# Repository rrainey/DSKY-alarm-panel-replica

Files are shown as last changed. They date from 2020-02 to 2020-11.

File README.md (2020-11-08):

# DSKY Alarm Indicator Panel Replica

## The current PCB layout has passed testing.

This is a scale functional replica of the Alarm Indicator panel for the Apollo Guidance Computer. It is
designed to be part of a larger replica of the Display and Keyboard (DSKY) module of the AGC.

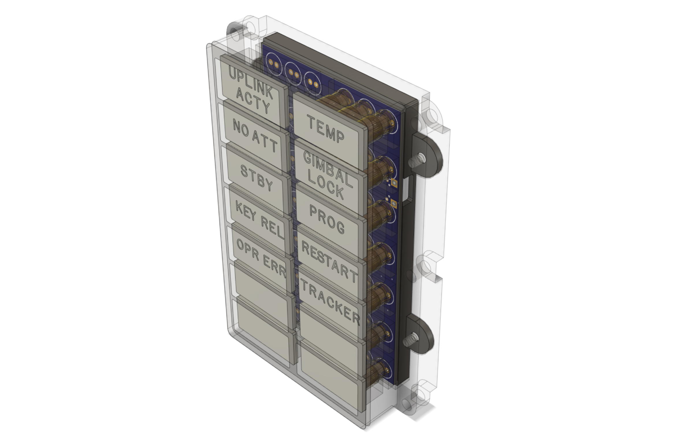
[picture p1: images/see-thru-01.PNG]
See through view


This project is composed of these component subfolders:

* artwork - artwork to be silk-screened onto the front transparent acrylic cover

* pcb - KiCad project for the controller PCB design

* firmware - circuitpython board definition and python-based test and controller firmware

* hardware - 3D-printable frame components designed using Fusion 360. STEP and Fusion source files available. Hardware models used in thie replica were derived from models found in the [AGC Mechanical CAD project](https://github.com/rrainey/agc-mechanical-cad).

## Exploded View of the Assembly

[This video](https://vimeo.com/393337269) will give you a sense of the internal construction of the unit. The panel
is a combinaton of white and yellow indicators. Like the original, incendescent lamps are used for each alarm
indicator. Yellow bezel inserts supply the indictor color where needed. An AT SAMD21 microcontroller drives the lamp from a 5V DC power
source. This microcontroller includes an I2C interface designed to be the source for external control of the unit.
There's also a USB interface, however, that's more for programming than operational use.

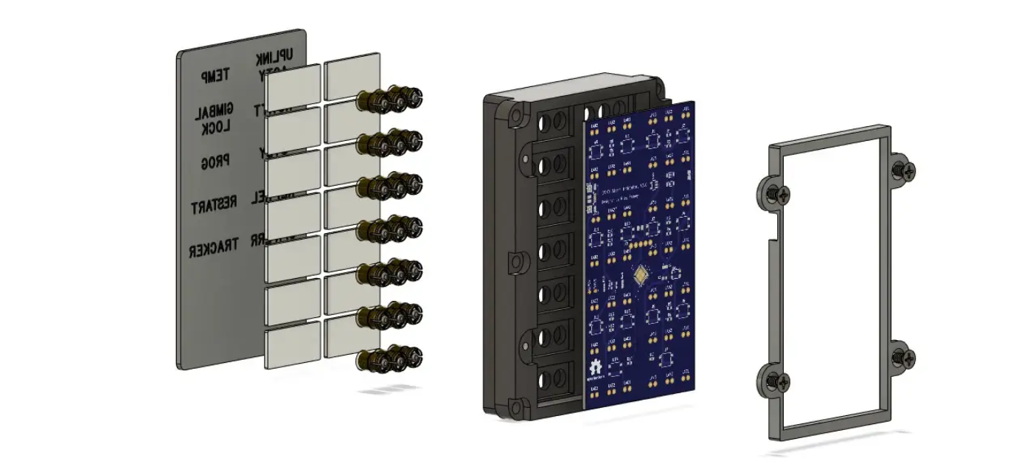
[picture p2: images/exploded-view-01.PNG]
Exploded view


At the top is a clear acrylic plate (0.060" thick). On that, I silkscreen lamp labels and the frame outline. Below that, there are 14 translucent covers, one for each indicator lamp array. Each indicator is composed of three incandescent lamps. Yellow bezels are inserted where needed. The bezels and the translucent covers snap into the main body of the component.  

A lamp and microcontroller PCB slides into a recess under the main body.  This PCB is held in place by a frame. The frame is secured with screws. The main body and PCB frame are both designed to be 3D printed from Nylon, ABS, or PLA.

## Painting

The original NASA drawings for all variants of this component, [1006387D for example,](https://archive.org/stream/apertureCardBox439Part2NARASW_images#page/n409/mode/1up) point to [this NASA paint specification [1008809-1]](https://archive.org/stream/apertureCardBox443NARASW_images#page/n504/mode/1up). It states [FED-STD 36231](http://federalstandard595.com/36231/) as the external color of the unit.  Good quality historial photos (examples [here](https://www.icollector.com/Apollo-CM-DSKY_i21861898) and [here](http://nassp.sourceforge.net/wiki/File:DSKY.jpg)) seem to imply a slightly different shade of gray, though. 

I haven't decided how to reconcile this difference yet. I may custom mix using Nazdar pigments, or I might simply use [an aircraft-grade epoxy premix](https://www.skygeek.com/deft-01-series-epoxy-topcoat-gray-36231-mil-prf-227750g.html) of FS36231.

## Credits and Related Projects

This project is inspired by work by Ben Krasnow creating a DSKY Electroluminescent Panel replica. You'll
find information about that project in [this Applied Science video](https://www.youtube.com/watch?v=Z2o_Sp2-aBo) by Ben. Like Ben's E/L display, this project is driven by an AT SAMD21 microcontroller chip; the same chip is used in the multiple Adafruit microcontroller boards, including the Adafruit Trinket M0.

## DSKY Alarm Indicator Replica License

Creative Commons Attribution/Share-Alike, all text above must be included in any redistribution. See license.txt for additional details.

## Adafruit Trinket M0 License

This project includes hardware design elements from the Adafruit [Trinket M0 PCB project](https://github.com/adafruit/Adafruit-Trinket-M0-PCB). Adafruit invests time and resources providing this open source design, please support Adafruit and open-source hardware by purchasing products from [Adafruit](https://www.adafruit.com)!

The Trinket M0 was designed by Limor Fried/Ladyada for Adafruit Industries.

Creative Commons Attribution/Share-Alike, all text above must be included in any redistribution. See license.txt for additional details.

## My Background

My name is Riley Rainey. I'm a software developer by profession. I spent a number of years building aerospace simulations as my day job.

## Getting Support

There's no official support available, but you can [leave comments or create an issue](https://github.com/rrainey/DSKY-alarm-panel-replica/issues) in this GitHub project.

  
This work is licensed under a [Creative Commons Attribution-ShareAlike 4.0 International License](http://creativecommons.org/licenses/by-sa/4.0/).

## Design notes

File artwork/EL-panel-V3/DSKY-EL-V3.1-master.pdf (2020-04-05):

DSKY-EL-V3.1-master.psd @ 66.7% (Conductive, RGB/8) *

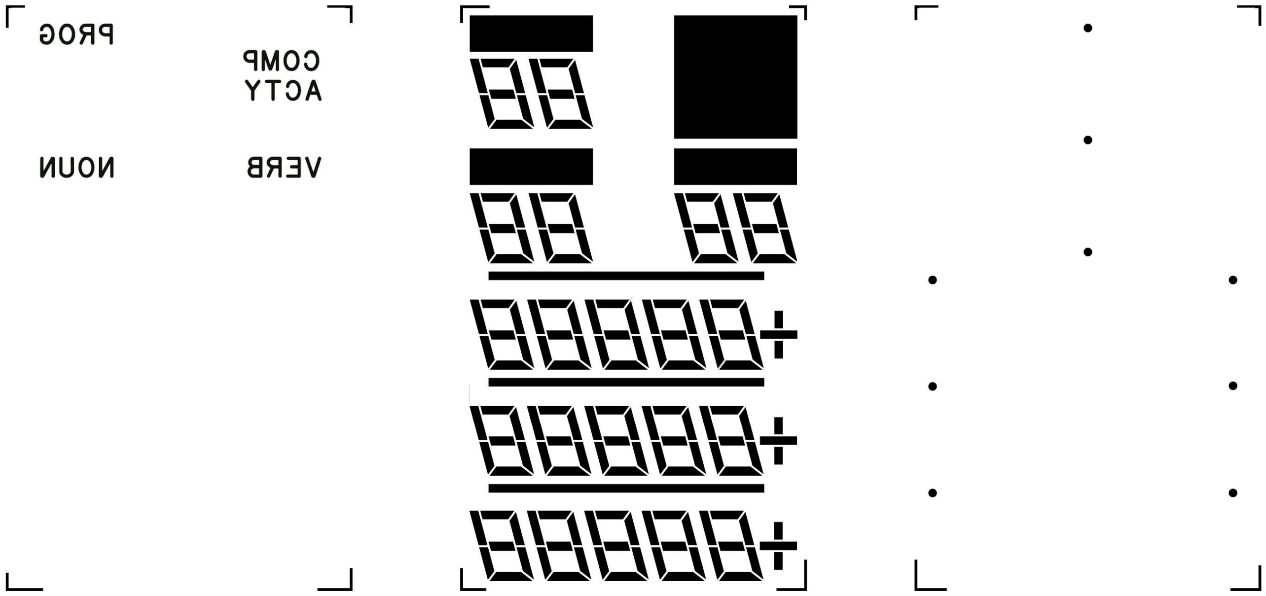
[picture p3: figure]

NOTE: ink laid down on the back side of ITO glass plate, so image appears reversed here. Glass dimensions 2.48x4.20 in.

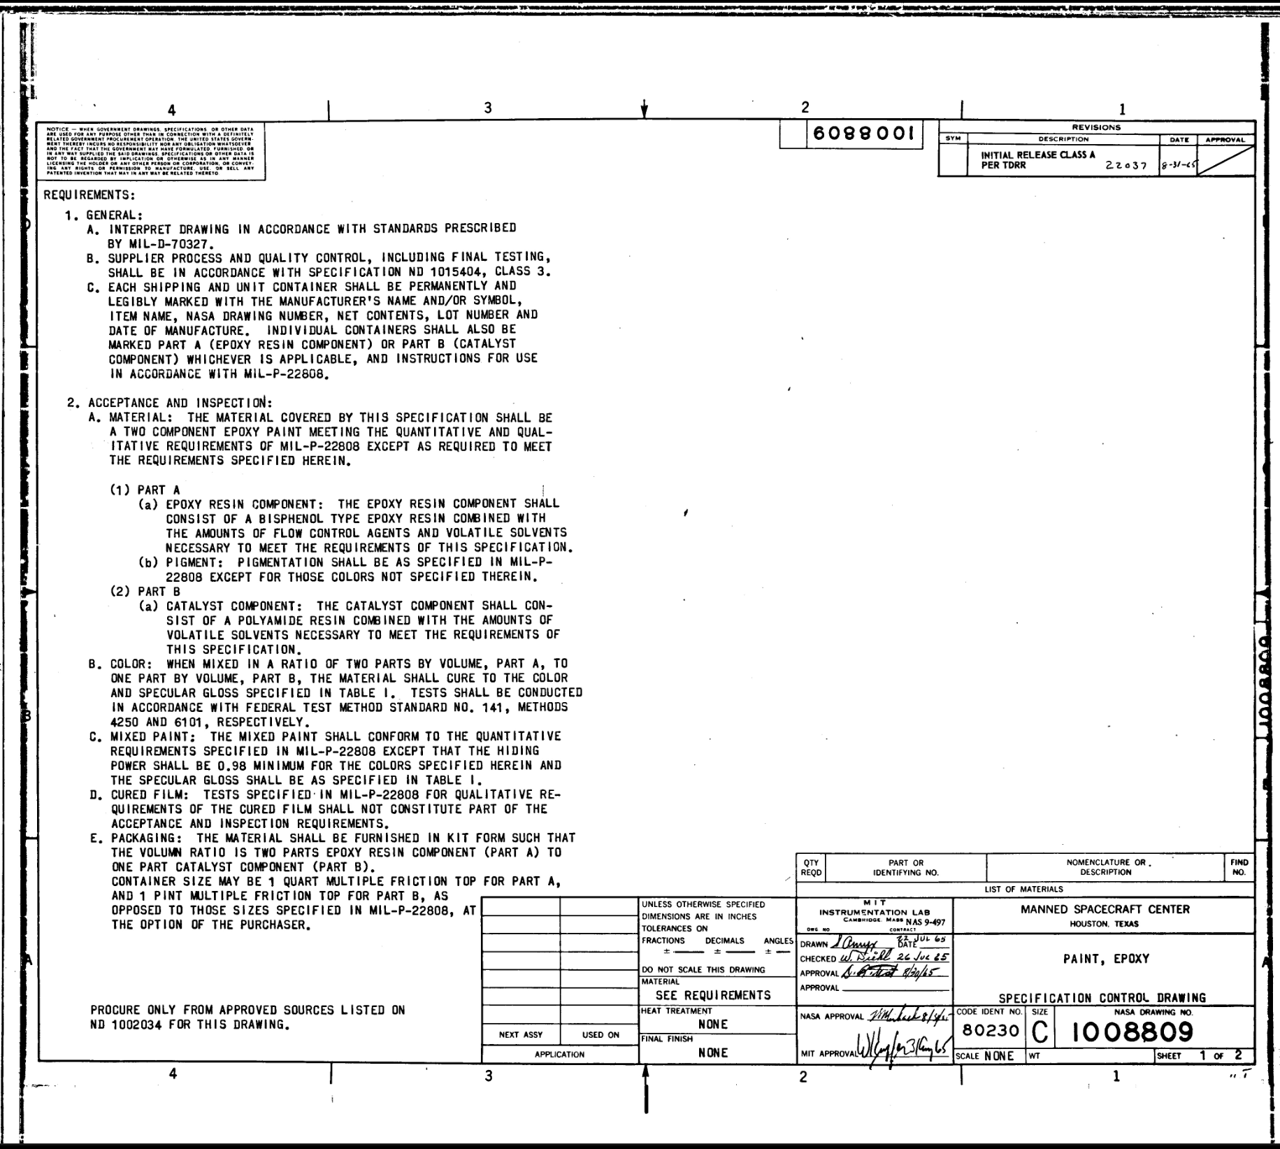
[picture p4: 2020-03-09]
images/1008809-1of2.PNG

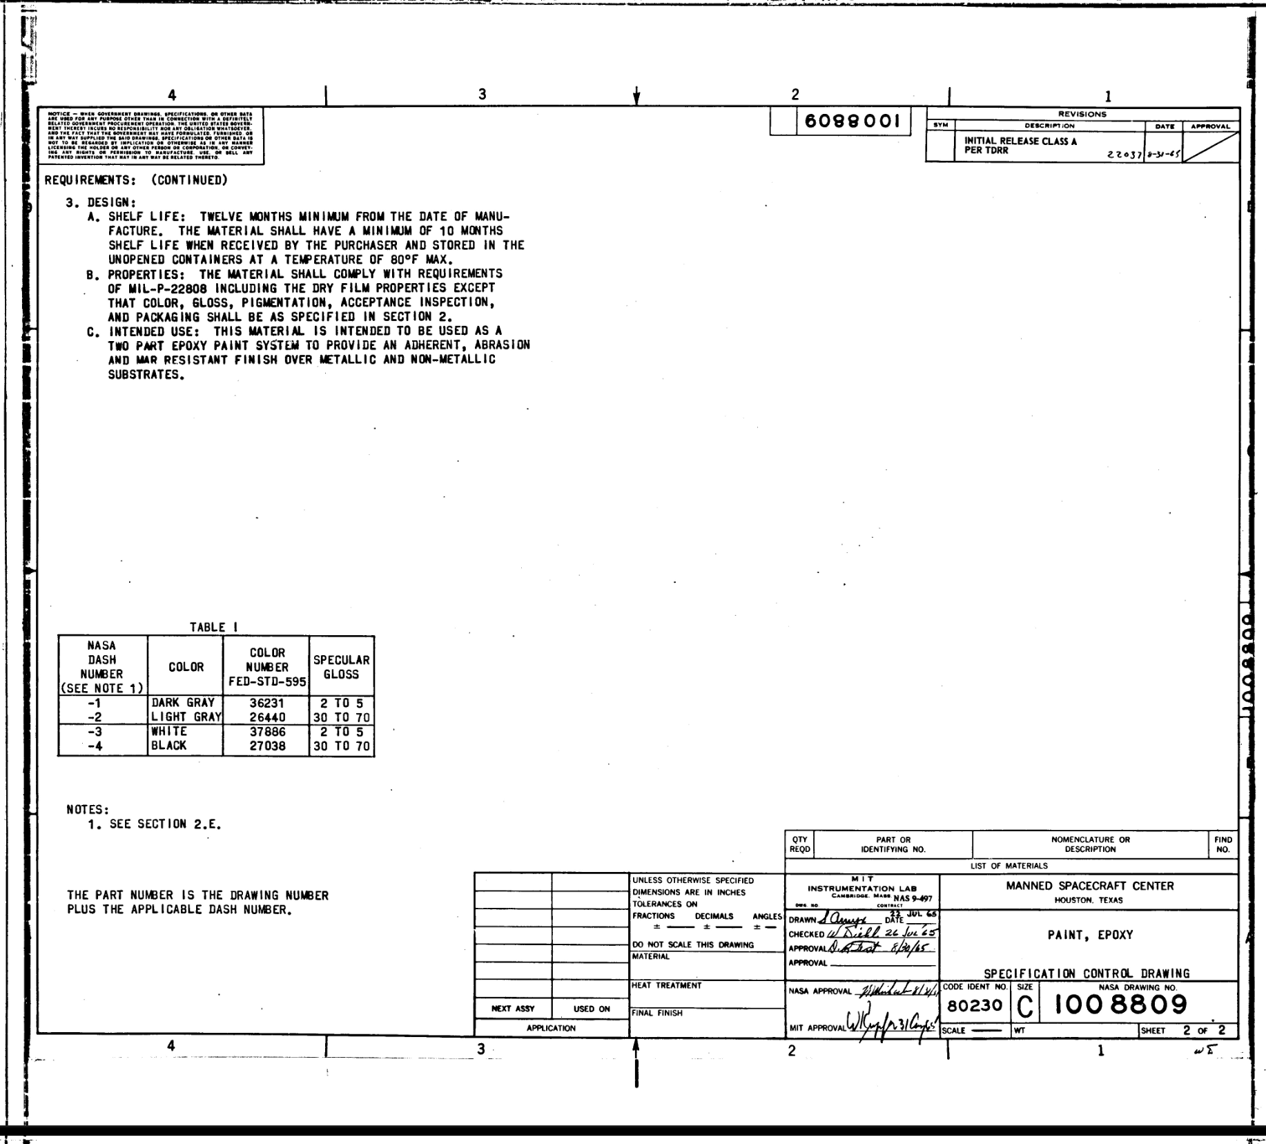
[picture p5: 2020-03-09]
images/100809-2of2.PNG

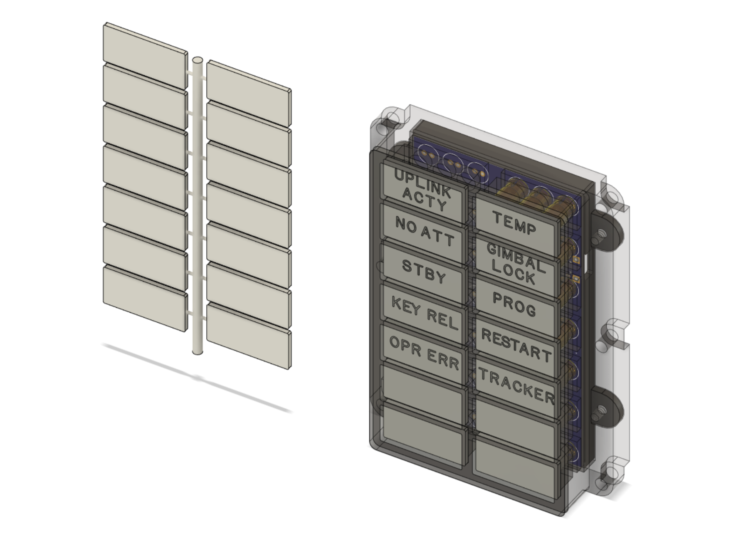
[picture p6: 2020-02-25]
images/insert-tree.PNG

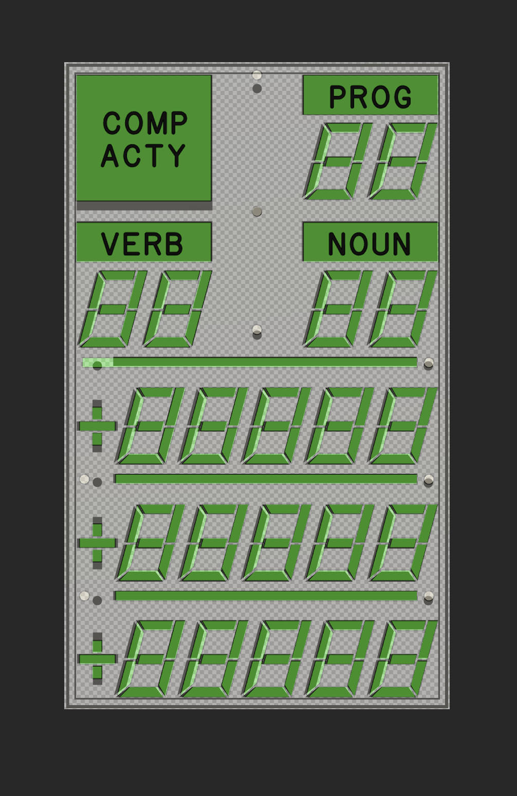
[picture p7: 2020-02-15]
artwork/EL-panel-V3/compare.PNG

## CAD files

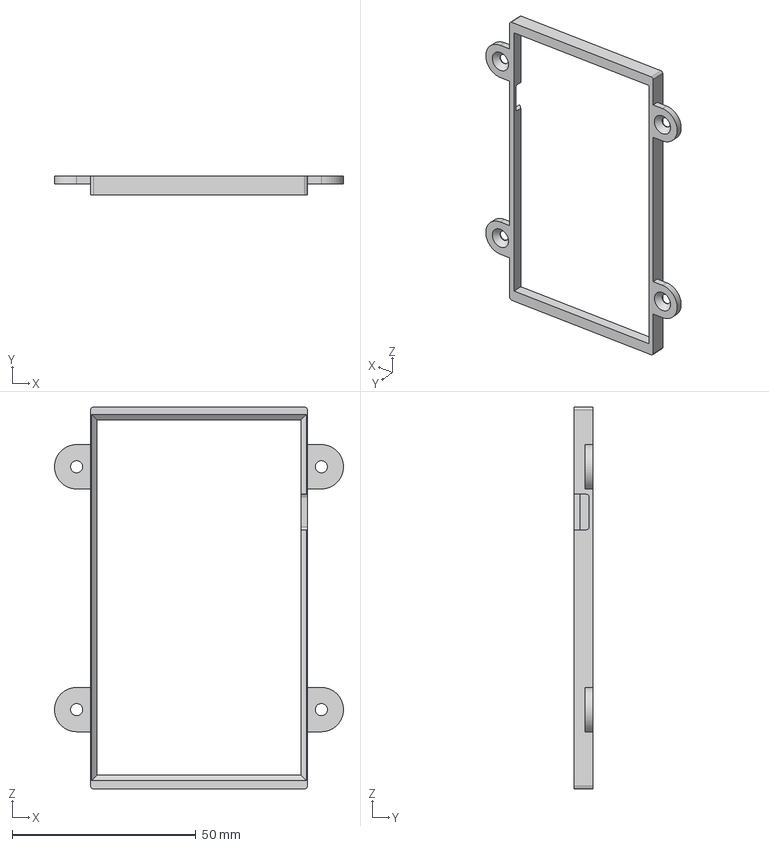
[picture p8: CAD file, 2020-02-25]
hardware/Retainer Plate.step
78.6 x 5.08 x 103.9 mm

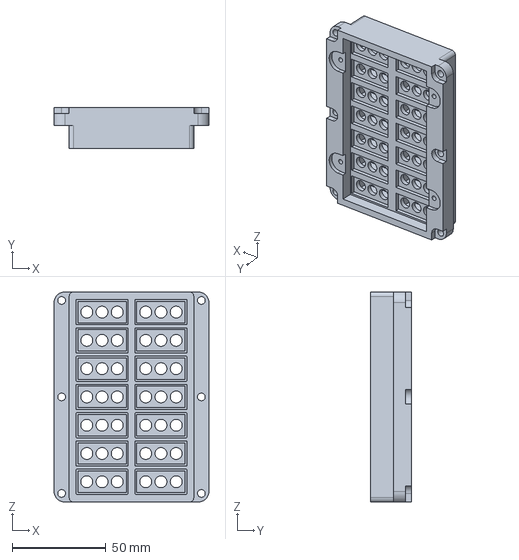
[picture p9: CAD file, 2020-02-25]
hardware/Frame.step
82.8 x 21.8 x 112.2 mm

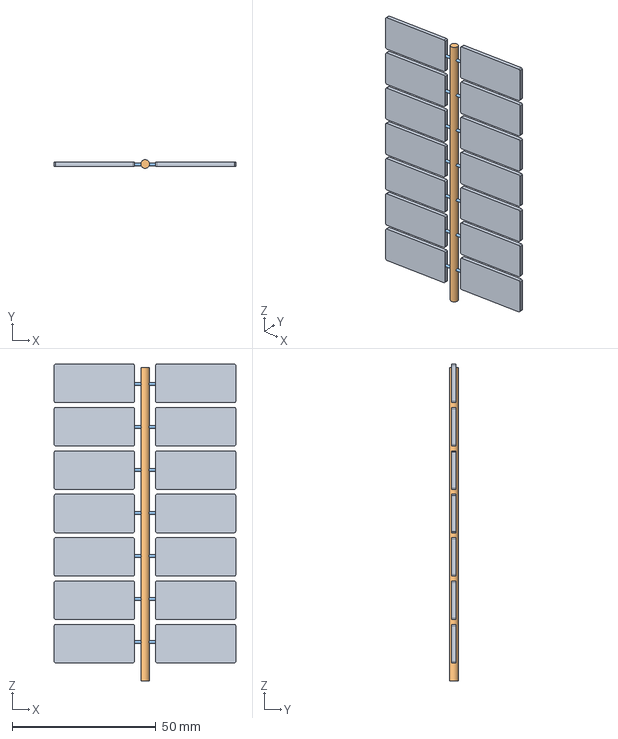
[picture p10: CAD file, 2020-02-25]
hardware/Translucent inserts tree.step
63.2 x 3.05 x 110.4 mm

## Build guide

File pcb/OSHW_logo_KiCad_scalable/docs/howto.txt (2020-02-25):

How to make your own:
---------------------

Watch / read this first:

* http://www.kicad-pcb.org/display/KICAD/Videos+by+zupnikal

The last two videos should be helpful for how to create a custom .emp file from images.

* http://www.re-innovation.co.uk/web12/index.php/en/blog-75/230-adding-logo-to-kicad

If you use linux (which you should), you don't have to use the online-scaler. Just use the scripts!

---

* Create a folder to hold your new footprint library.
* Copy the scripts 'make_lib.sh' and 'scale.pl' into that folder.
* Make sure these files are executable (chmod u+x ...).
* Copy your custom .emp file into that foler.

* Run the 'make_lib.sh' script as follows:

./make_lib.sh input-file.emp lib-name.mod START END

START and END are placeholders for positive integer numbers (1,2,3...) that determine
the range of created footprint sizes. The units are metric (mm).

The 'lib-name.mod' file will show up in the 'lib' sub-folder. Add it to your pcbnew
library settings as usual.

Footprints that are created for back-layers are automagically mirrored horizontally.
To place them onto a back-layer, hover the mouse-pointer over them and press 'f' for 'flip'.

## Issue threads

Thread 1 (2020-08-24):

Arduino build doesn't yet appear to support all output required output pins

rrainey, 2020-08-24:
I have modified the Adafruit trinket_m0 Arduino SAMD board definition to insert references to all output pins used by the design, but this isn't working quite yet.  See https://github.com/adafruit/ArduinoCore-samd

rrainey, 2020-09-25:
The modified board definition seems to be working. I'll publish the updated variant.cpp file separately.

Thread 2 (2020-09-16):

Merge into CircuitPython?

tannewt, 2020-09-16:
This is very cool! Do you plan on merging the board definition into main CircuitPython? We'd love to have it.

rrainey, 2020-09-26:
Ya. Let me back up a bit and look into it. I rewrote the I2C driver firmware as an Arduino sketch, however, that was mainly to be more consistent with Ben Krasnow's DSKY EL Driver project. I hadn't worked with CircuitPython before this project and I came to like it pretty quickly -- even with the board-specific changes that I needed to add. I have really enjoyed working with Adafruit's line of SAM boards and firmware. The openness is fabulous. It made for an easy jumping off point for creating these custom PCB designs. keep up the great work!

rrainey, 2020-09-26:
I'll spend some time on it this weekend. I see that my CircuitPython board definition requires a few digital pin additions to reflect the current lamp configuration. I'll send y'all a PR when I'm done.

tannewt, 2020-09-26:
Great! Feel free to check in on the Adafruit Discord if you have any questions: https://adafru.it/discord

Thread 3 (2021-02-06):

Bill of materials

vladamihailescu, 2021-02-06:
Hello Riley,

I was just wondering if you had a BOM for the alarm panel. The one I generated from your Kicad is missing the part numbers for the capacitors and diodes

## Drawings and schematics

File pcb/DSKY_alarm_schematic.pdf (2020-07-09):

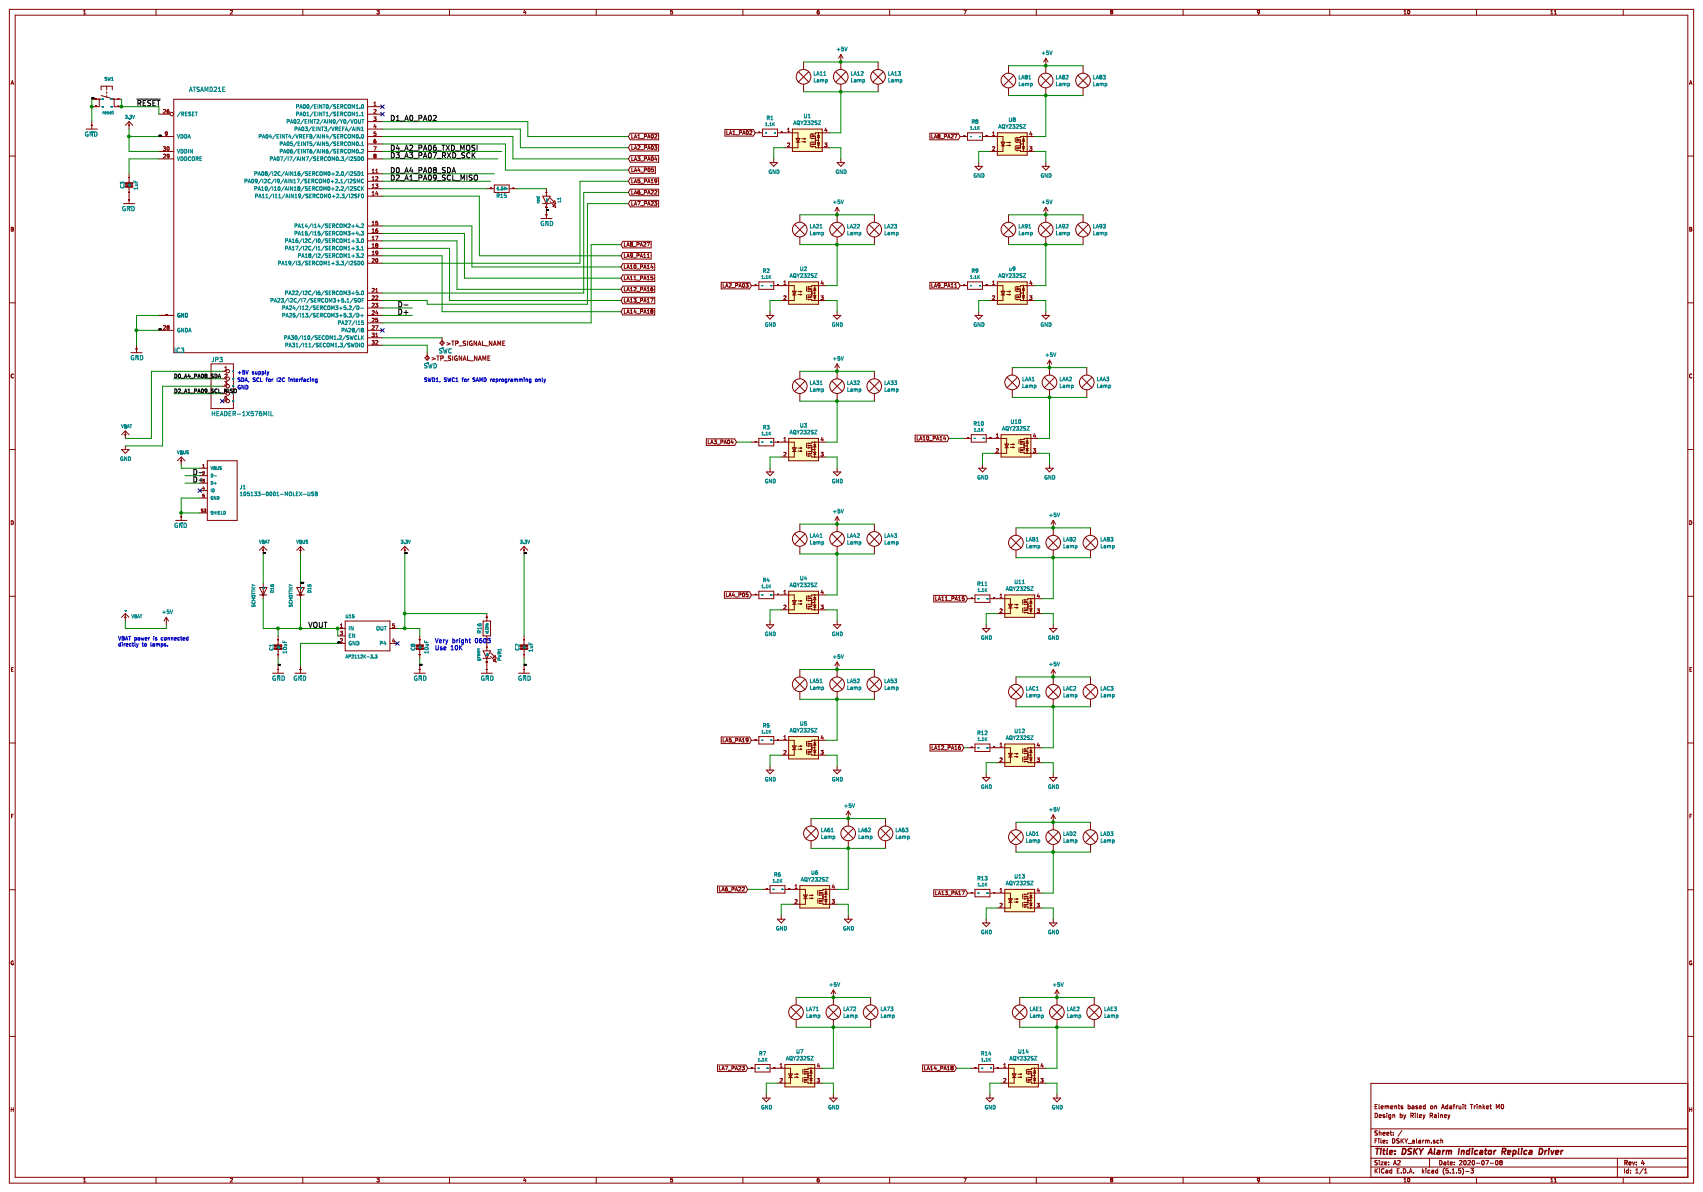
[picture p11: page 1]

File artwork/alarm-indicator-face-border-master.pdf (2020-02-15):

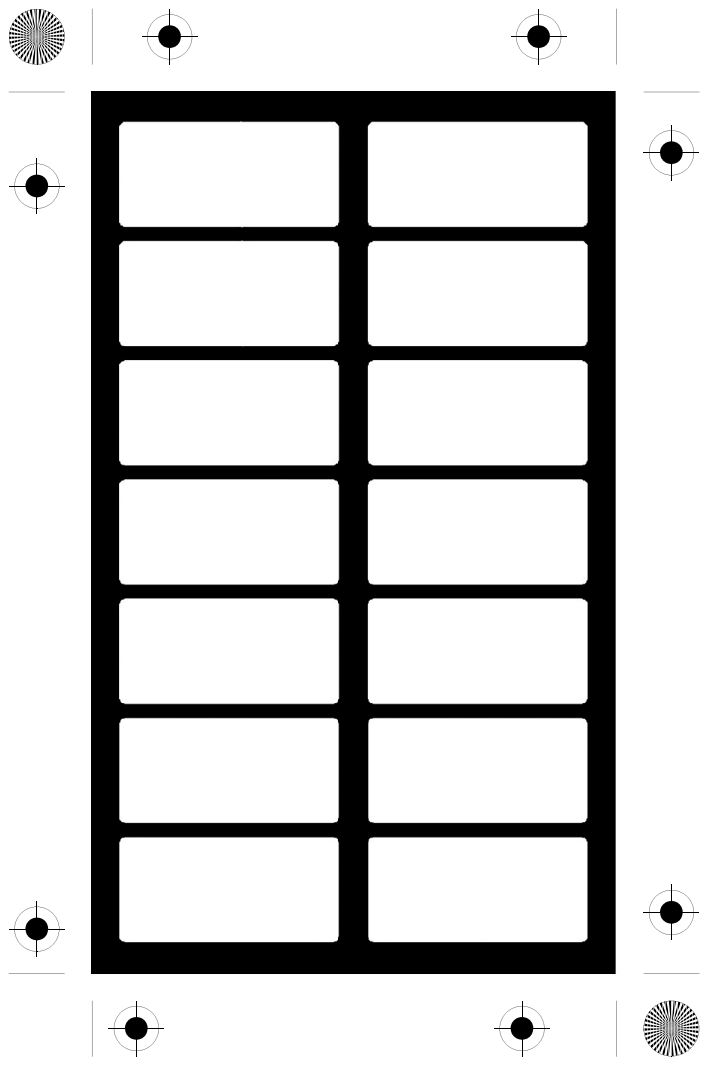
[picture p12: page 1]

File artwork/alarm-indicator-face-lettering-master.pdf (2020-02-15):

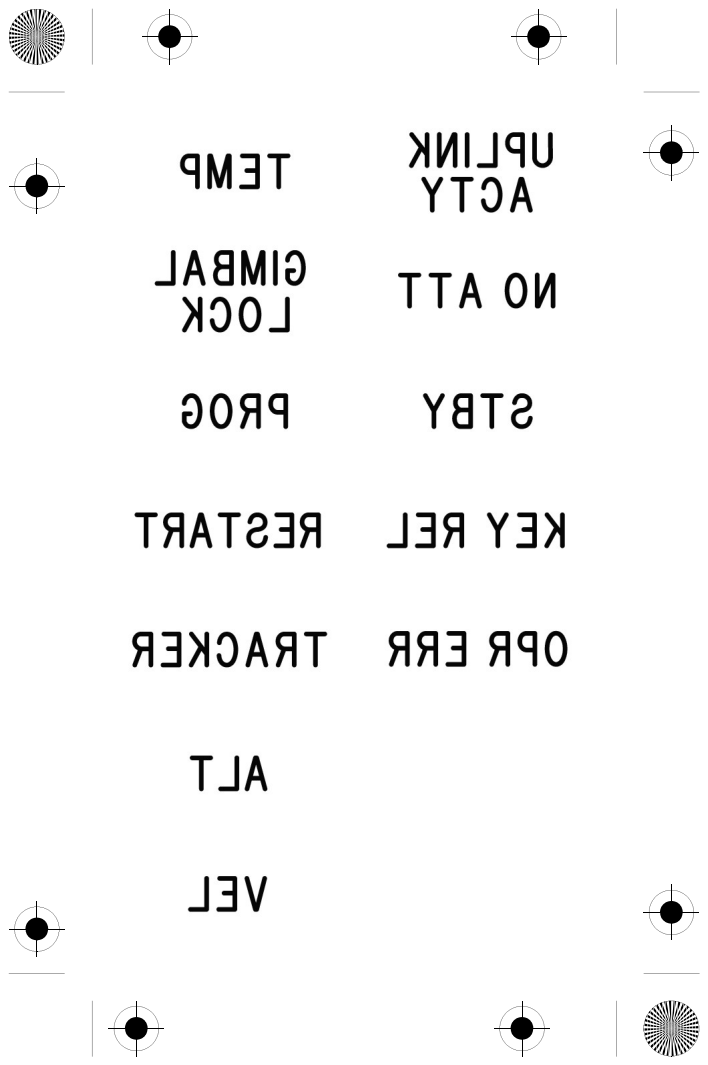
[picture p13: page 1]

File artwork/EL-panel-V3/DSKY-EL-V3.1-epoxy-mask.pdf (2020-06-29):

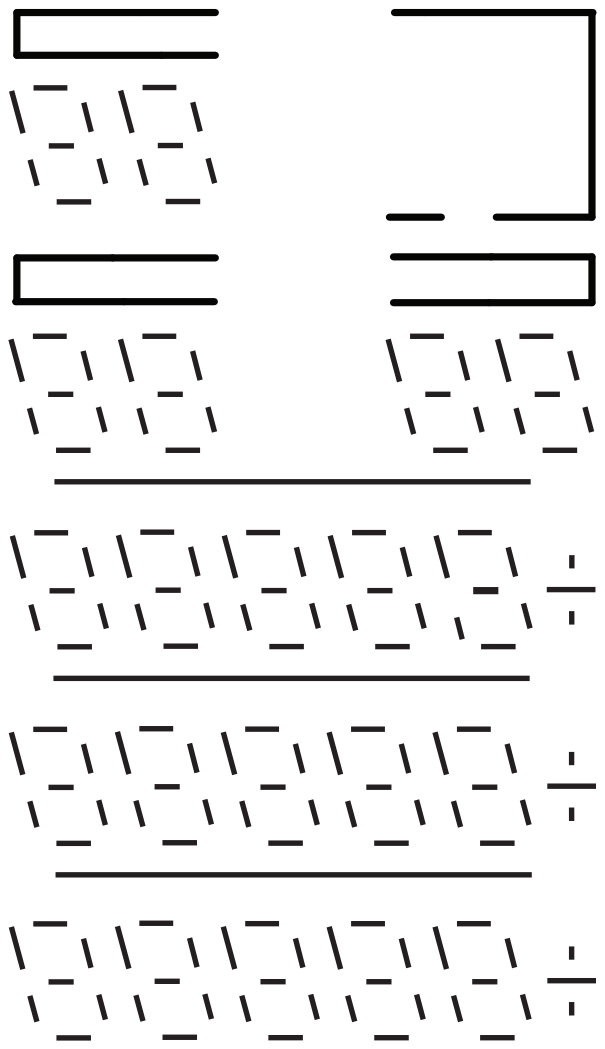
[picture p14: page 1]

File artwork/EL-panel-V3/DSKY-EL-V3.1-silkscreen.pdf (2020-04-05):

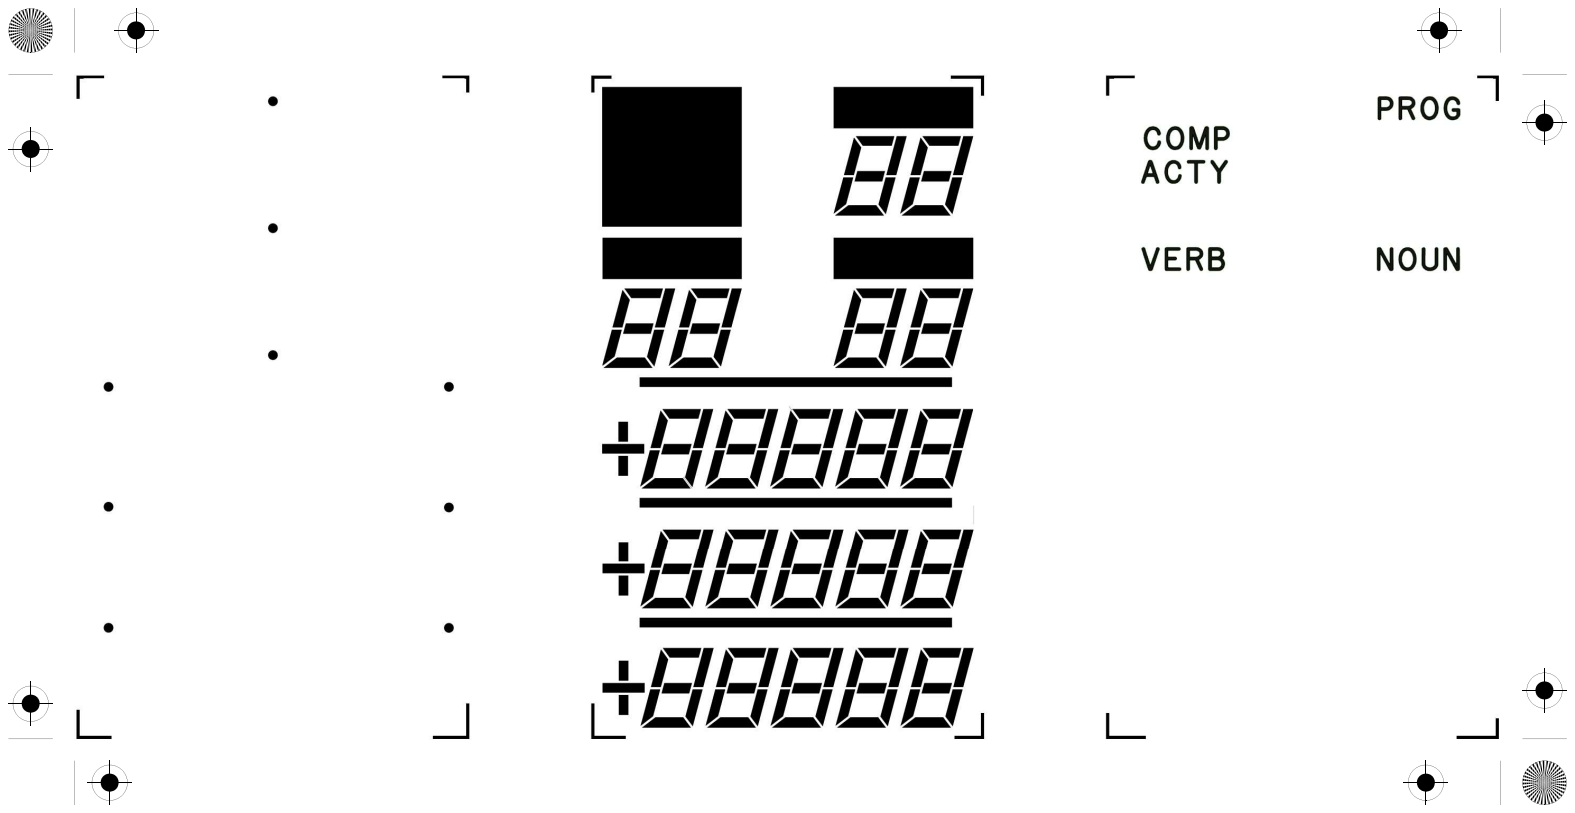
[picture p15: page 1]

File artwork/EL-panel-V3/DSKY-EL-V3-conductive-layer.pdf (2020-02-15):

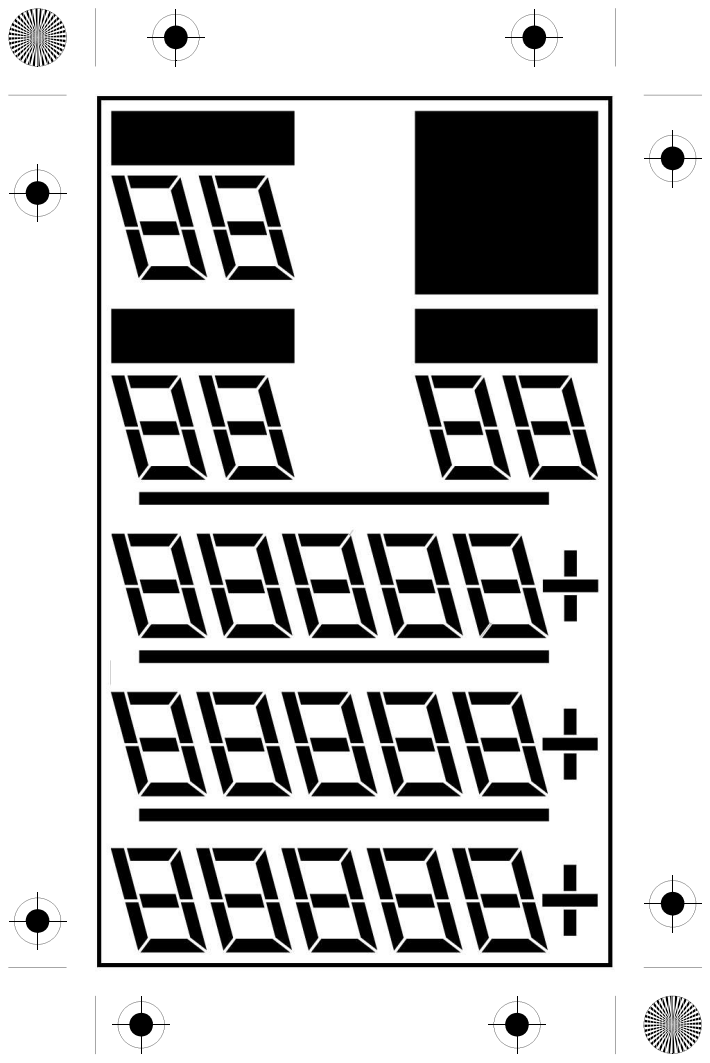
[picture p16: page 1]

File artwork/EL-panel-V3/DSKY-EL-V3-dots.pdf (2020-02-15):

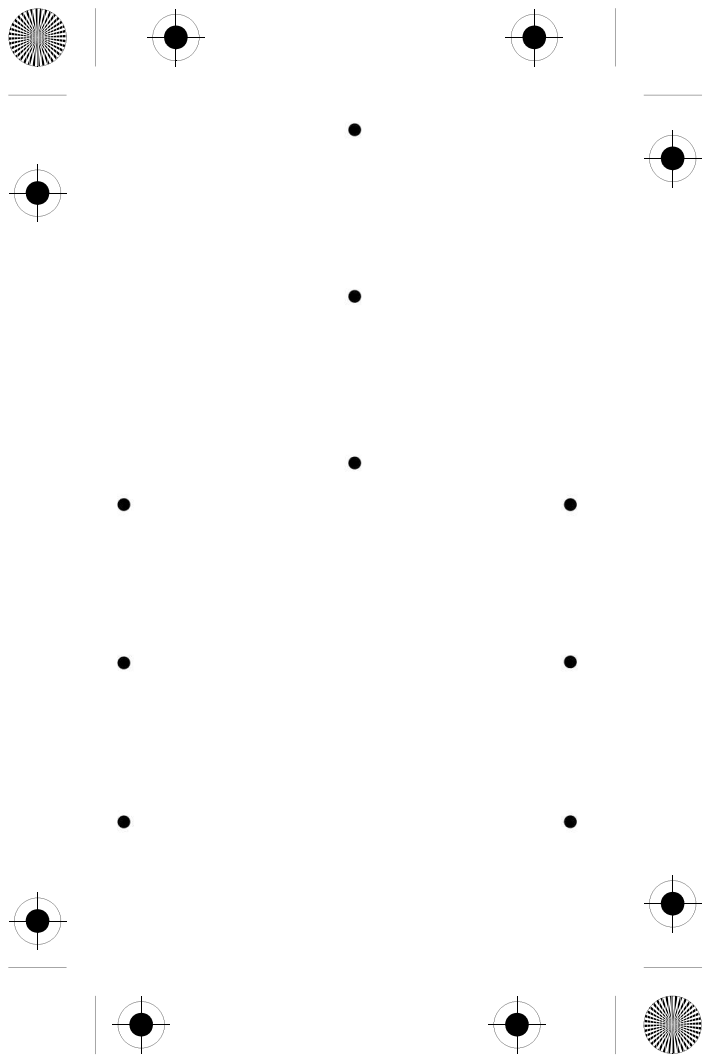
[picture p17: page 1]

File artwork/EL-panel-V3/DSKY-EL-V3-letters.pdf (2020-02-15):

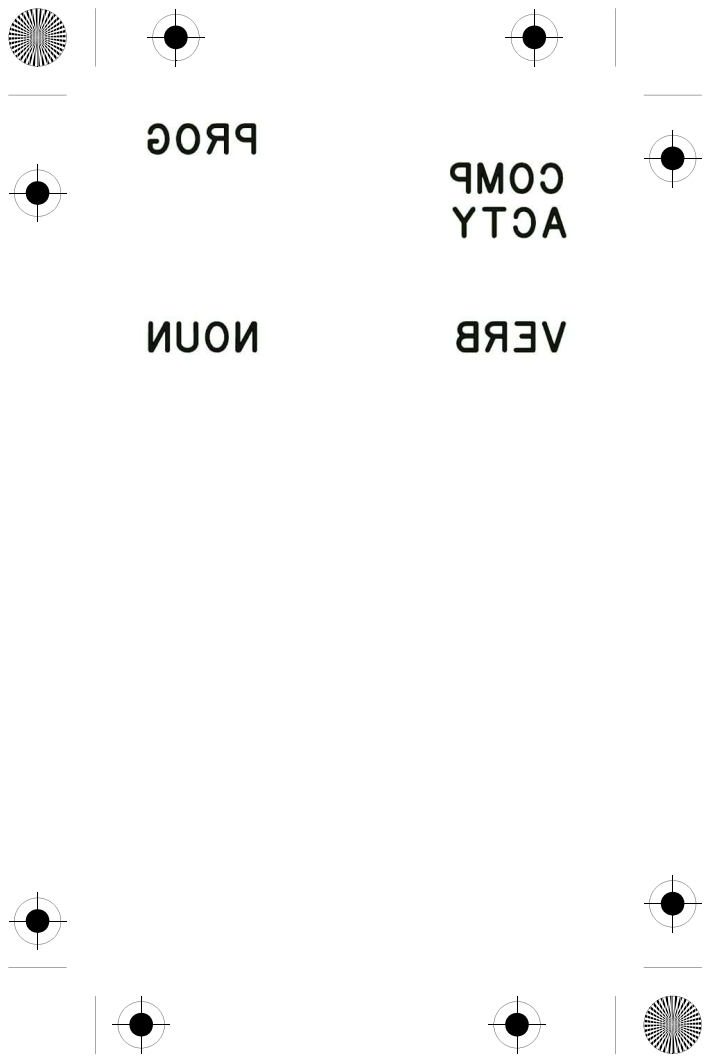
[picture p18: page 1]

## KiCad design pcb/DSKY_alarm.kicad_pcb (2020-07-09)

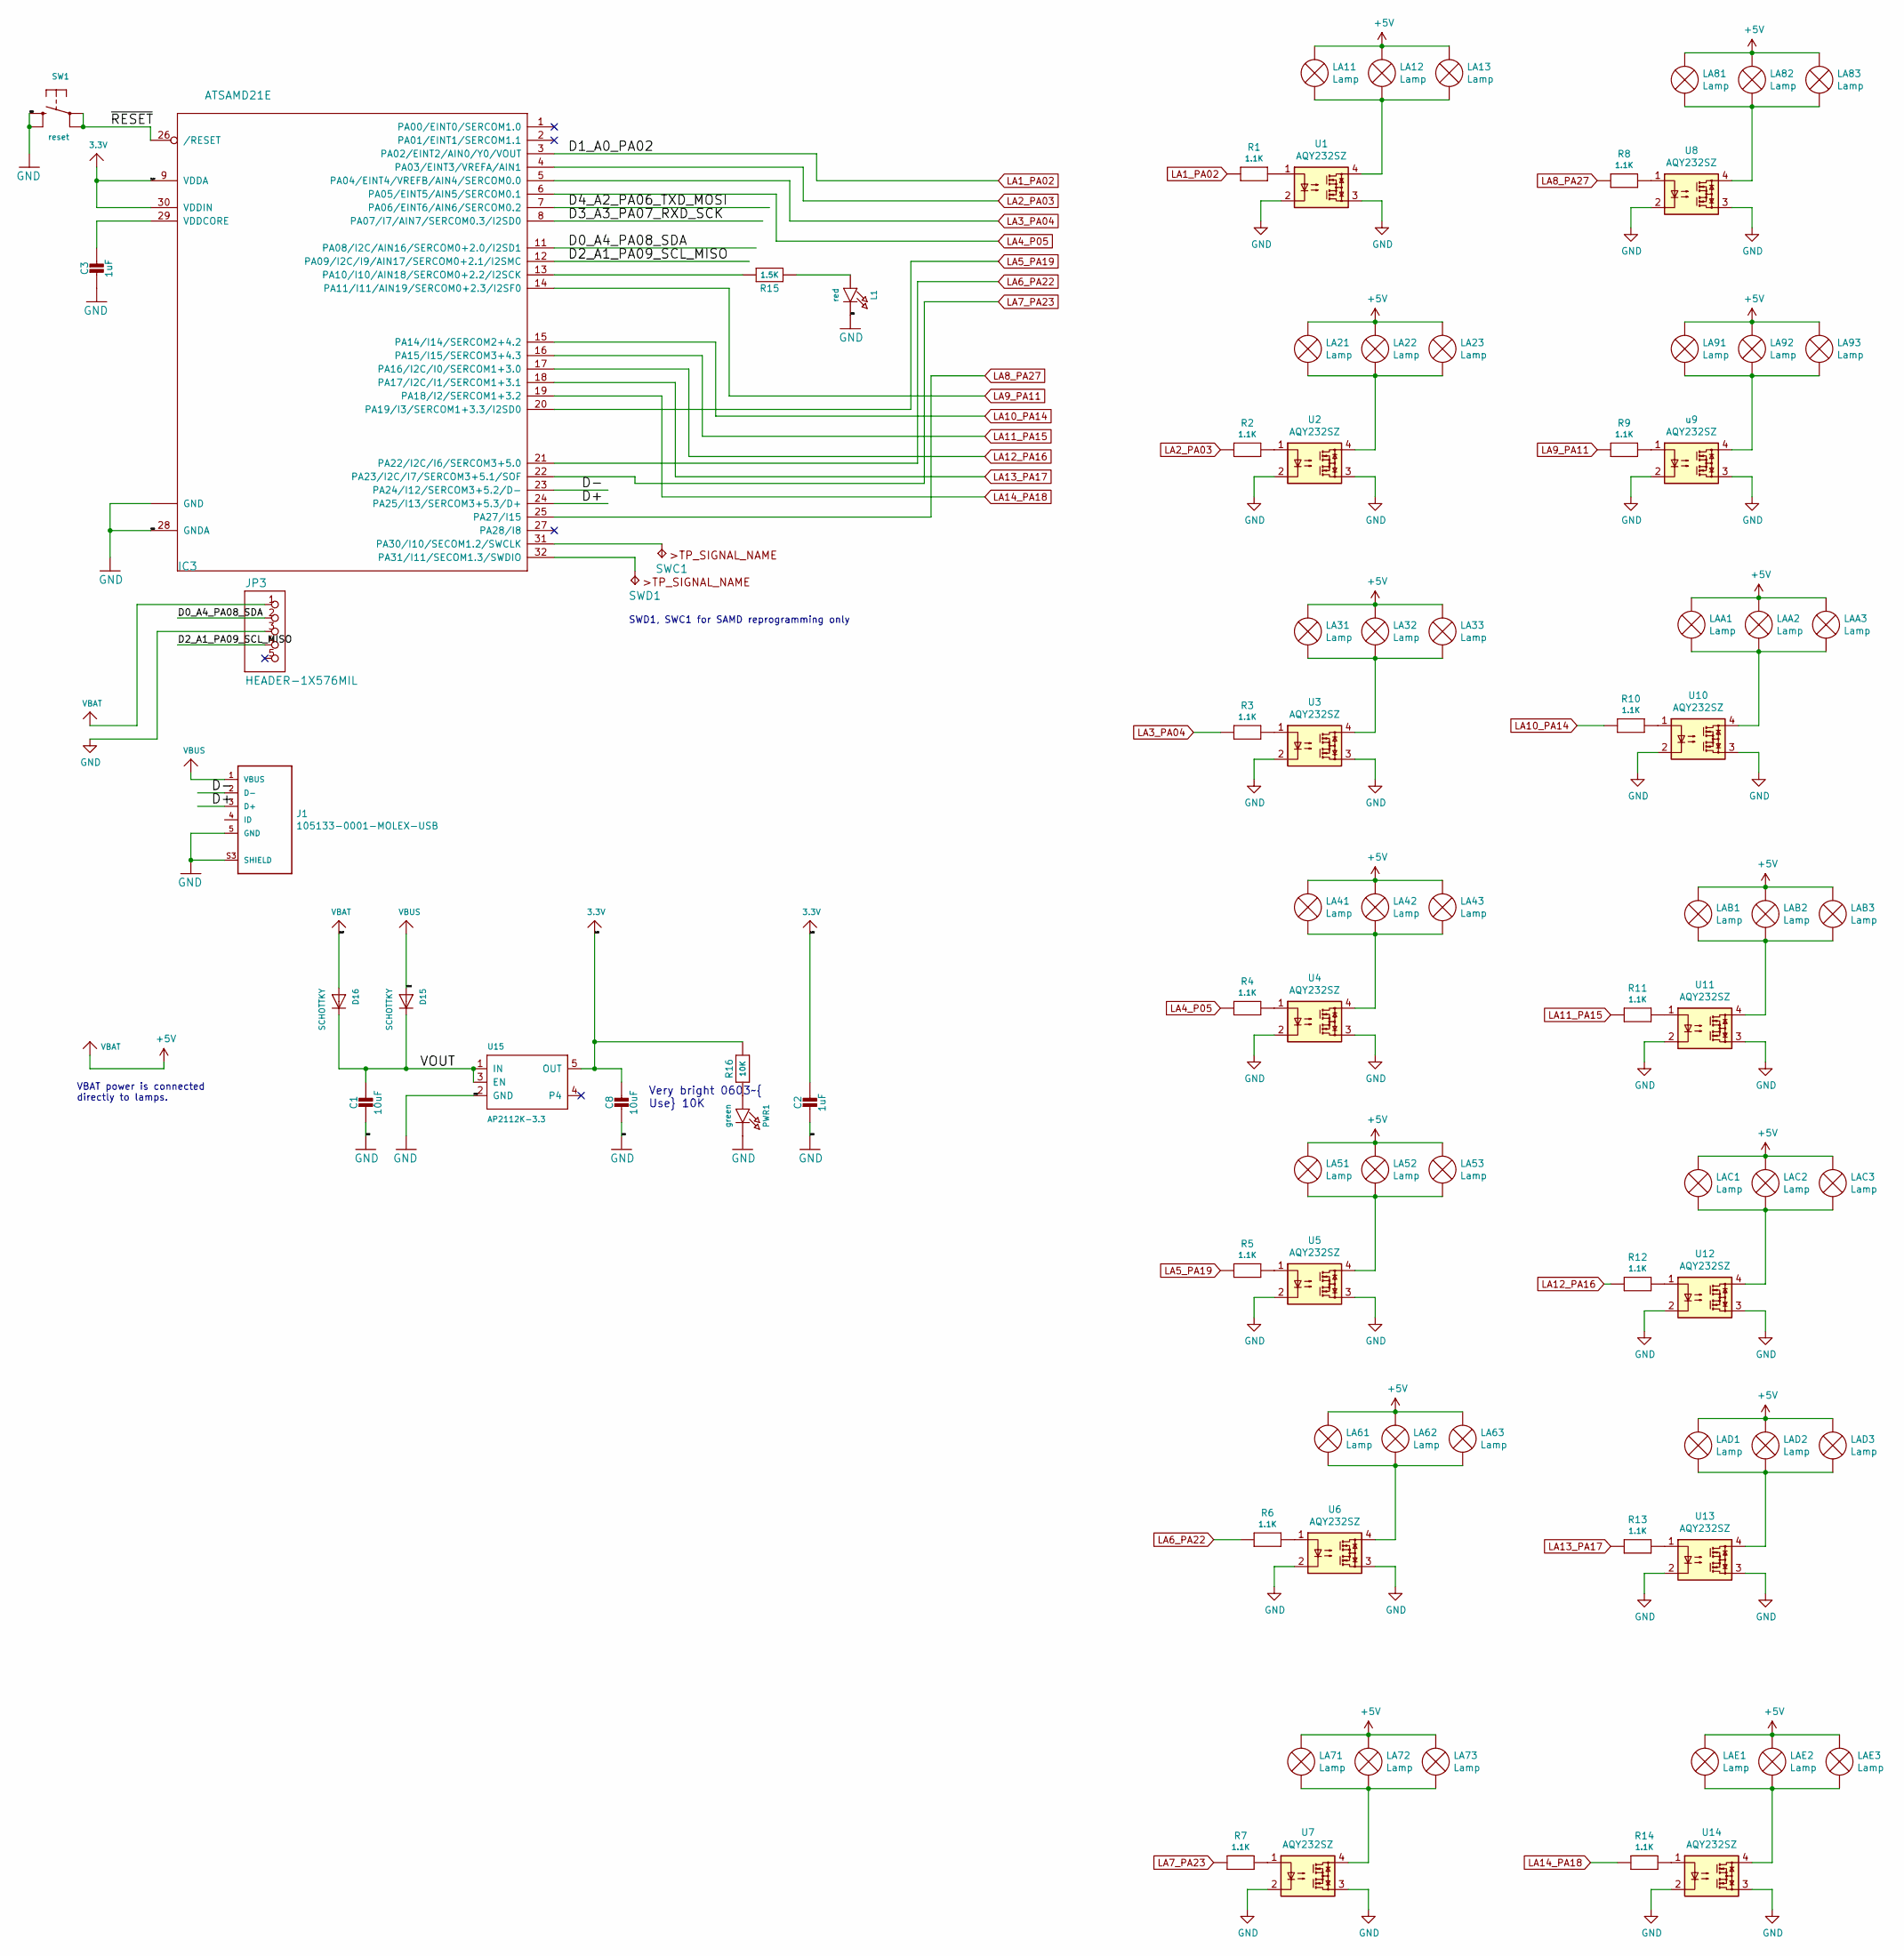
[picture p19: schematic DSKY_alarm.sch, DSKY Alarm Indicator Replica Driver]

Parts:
C1, C8: 10uF; 0805-NO
C2, C3: 1uF; 0603-NO
D15, D16: SCHOTTKY; SOD-123FL
IC3: ATSAMD21E; QFN32_5MM
J1: 105133-0001-MOLEX-USB; MOLEX_105133-0001
JP3: HEADER-1X576MIL; 1X05_ROUND_76
L1: red; CHIPLED_0603_NOOUTLINE
LA11, LA12, LA13, LA21, LA22, LA23, LA31, LA32, LA33, LA41, LA42, LA43, LA51, LA52, LA53, LA61, LA62, LA63, LA71, LA72, LA73, LA81, LA82, LA83, LA91, LA92, LA93: Lamp; VCC7216-ND
LAA1, LAA2, LAA3: Lamp; VCC7216-ND
LAB1, LAB2, LAB3: Lamp; VCC7216-ND
LAC1, LAC2, LAC3: Lamp; VCC7216-ND
LAD1, LAD2, LAD3: Lamp; VCC7216-ND
LAE1, LAE2, LAE3: Lamp; VCC7216-ND
PWR1: green; CHIPLED_0603_NOOUTLINE
R1, R2, R3, R4, R5, R6, R7, R8, R9, R10, R11, R12, R13, R14: 1.1K; R_0603_1608Metric
R15: 1.5K; 0603-NO
R16: 10K; 0603-NO
SW1: reset; BTN_KMR2_4.6X2.8
SWC1: TPB1,27; B1,27
SWD1: TPB1,27; B1,27
U1, U2, U3, U4, U5, U6, U7, U8, U10, U11, U12, U13, U14: AQY232SZ; SO-4_4.4x4.3mm_P2.54mm
U15: AP2112K-3.3; SOT23-5
u9: AQY232SZ; SO-4_4.4x4.3mm_P2.54mm

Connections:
3.3V: C2.1, C8.1, IC3.9 (VDDA), IC3.30 (VDDIN), R16.2, U15.5 (OUT)
+5V: D16.A, JP3.1, LA11.2 (+), LA12.2 (+), LA13.2 (+), LA21.2 (+), LA22.2 (+), LA23.2 (+), LA31.2 (+), LA32.2 (+), LA33.2 (+), LA41.2 (+), LA42.2 (+), LA43.2 (+), LA51.2 (+), LA52.2 (+), LA53.2 (+), LA61.2 (+), LA62.2 (+), LA63.2 (+), LA71.2 (+), LA72.2 (+), LA73.2 (+), LA81.2 (+), LA82.2 (+), LA83.2 (+), LA91.2 (+), LA92.2 (+), LA93.2 (+), LAA1.2 (+), LAA2.2 (+), LAA3.2 (+), LAB1.2 (+), LAB2.2 (+), LAB3.2 (+), LAC1.2 (+), LAC2.2 (+), LAC3.2 (+), LAD1.2 (+), LAD2.2 (+), LAD3.2 (+), LAE1.2 (+), LAE2.2 (+), LAE3.2 (+)
/D0_A4_PA08_SDA: IC3.11 (PA08/I2C/AIN16/SERCOM0+2.0/I2SD1), JP3.2
/D2_A1_PA09_SCL_MISO: IC3.12 (PA09/I2C/I9/AIN17/SERCOM0+2.1/I2SMC), JP3.4
/D3_A3_PA07_RXD_SCK: IC3.8 (PA07/I7/AIN7/SERCOM0.3/I2SD0)
/D4_A2_PA06_TXD_MOSI: IC3.7 (PA06/EINT6/AIN6/SERCOM0.2)
/D+: IC3.24 (PA25/I13/SERCOM3+5.3/D+), J1.3 (D+)
/D-: IC3.23 (PA24/I12/SERCOM3+5.2/D-), J1.2 (D-)
/VOUT: C1.1, D15.C, D16.C, U15.1 (IN), U15.3 (EN)
/~RESET: IC3.26 (/RESET), SW1.A, SW1.A' (P1)
GND: C1.2, C2.2, C3.2, C8.2, IC3.10 (GND), IC3.28 (GNDA), IC3.33 (GND), J1.5 (GND), J1.S3 (SHIELD), JP3.3, L1.C, PWR1.C, SW1.B (S), SW1.B' (S1), U1.2, U1.3, U2.2, U2.3, U3.2, U3.3, U4.2, U4.3, U5.2, U5.3, U6.2, U6.3, U7.2, U7.3, U8.2, U8.3, U10.2, U10.3, U11.2, U11.3, U12.2, U12.3, U13.2, U13.3, U14.2, U14.3, U15.2 (GND), u9.2, u9.3
LA1_PA02: IC3.3 (PA02/EINT2/AIN0/Y0/VOUT), R1.1
LA2_PA03: IC3.4 (PA03/EINT3/VREFA/AIN1), R2.1
LA3_PA04: IC3.5 (PA04/EINT4/VREFB/AIN4/SERCOM0.0), R3.1
LA4_P05: IC3.6 (PA05/EINT5/AIN5/SERCOM0.1), R4.1
LA5_PA19: IC3.20 (PA19/I3/SERCOM1+3.3/I2SD0), R5.1
LA6_PA22: IC3.21 (PA22/I2C/I6/SERCOM3+5.0), R6.1
LA7_PA23: IC3.22 (PA23/I2C/I7/SERCOM3+5.1/SOF), R7.1
LA8_PA27: IC3.25 (PA27/I15), R8.1
LA9_PA11: IC3.14 (PA11/I11/AIN19/SERCOM0+2.3/I2SF0), R9.1
LA10_PA14: IC3.15 (PA14/I14/SERCOM2+4.2), R10.1
LA11_PA15: IC3.16 (PA15/I15/SERCOM3+4.3), R11.1
LA12_PA16: IC3.17 (PA16/I2C/I0/SERCOM1+3.0), R12.1
LA13_PA17: IC3.18 (PA17/I2C/I1/SERCOM1+3.1), R13.1
LA14_PA18: IC3.19 (PA18/I2/SERCOM1+3.2), R14.1
unnamed: C3.1, IC3.29 (VDDCORE)
unnamed: IC3.13 (PA10/I10/AIN18/SERCOM0+2.2/I2SCK), R15.2
unnamed 30: IC3.31 (PA30/I10/SECOM1.2/SWCLK), SWC1.TP; also elsewhere on the board
unnamed 31: IC3.32 (PA31/I11/SECOM1.3/SWDIO), SWD1.TP; also elsewhere on the board
unnamed: L1.A, R15.1
unnamed: LA11.1 (-), LA12.1 (-), LA13.1 (-), U1.4
unnamed: LA21.1 (-), LA22.1 (-), LA23.1 (-), U2.4
unnamed: LA31.1 (-), LA32.1 (-), LA33.1 (-), U3.4
unnamed: LA41.1 (-), LA42.1 (-), LA43.1 (-), U4.4
unnamed: LA51.1 (-), LA52.1 (-), LA53.1 (-), U5.4
unnamed: LA61.1 (-), LA62.1 (-), LA63.1 (-), U6.4
unnamed: LA71.1 (-), LA72.1 (-), LA73.1 (-), U7.4
unnamed: LA81.1 (-), LA82.1 (-), LA83.1 (-), U8.4
unnamed: LA91.1 (-), LA92.1 (-), LA93.1 (-), u9.4
unnamed: LAA1.1 (-), LAA2.1 (-), LAA3.1 (-), U10.4
unnamed: LAB1.1 (-), LAB2.1 (-), LAB3.1 (-), U11.4
unnamed: LAC1.1 (-), LAC2.1 (-), LAC3.1 (-), U12.4
unnamed: LAD1.1 (-), LAD2.1 (-), LAD3.1 (-), U13.4
unnamed: LAE1.1 (-), LAE2.1 (-), LAE3.1 (-), U14.4
unnamed: PWR1.A, R16.1
unnamed: R1.2, U1.1
unnamed: R2.2, U2.1
unnamed: R3.2, U3.1
unnamed: R4.2, U4.1
unnamed: R5.2, U5.1
unnamed: R6.2, U6.1
unnamed: R7.2, U7.1
unnamed: R8.2, U8.1
unnamed: R9.2, u9.1
unnamed: R10.2, U10.1
unnamed: R11.2, U11.1
unnamed: R12.2, U12.1
unnamed: R13.2, U13.1
unnamed: R14.2, U14.1
VBUS: D15.A, J1.1 (VBUS)

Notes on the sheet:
Very bright 0603~ Use 10K
VBAT power is connected directly to lamps.
SWD1, SWC1 for SAMD reprogramming only

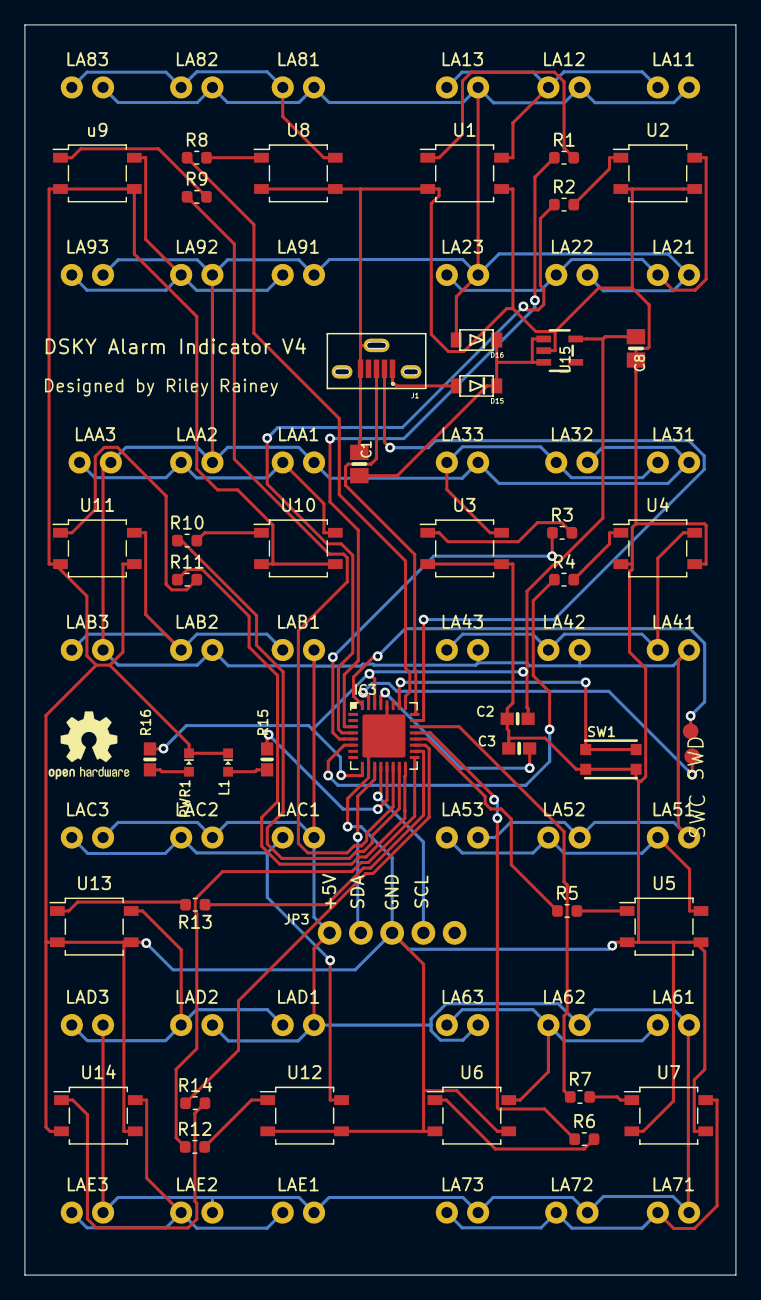
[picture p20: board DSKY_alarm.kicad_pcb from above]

Board: 2 copper layers, 57.8 x 101.6 mm, 87 parts (0 on the bottom side), 58 nets.

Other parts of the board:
SWC: TPB1,27; B1,27
SWD: TPB1,27; B1,27

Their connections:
unnamed 30: SWC.TP; also elsewhere on the board
unnamed 31: SWD.TP; also elsewhere on the board

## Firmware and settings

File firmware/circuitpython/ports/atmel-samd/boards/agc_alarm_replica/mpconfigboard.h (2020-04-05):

#define MICROPY_HW_BOARD_NAME "Adafruit Trinket M0"
#define MICROPY_HW_MCU_NAME "samd21e18"

// Rev B - Black
#define MICROPY_HW_LED_STATUS   (&pin_PA10)

#define MICROPY_HW_APA102_MOSI   (&pin_PA00)
#define MICROPY_HW_APA102_SCK    (&pin_PA01)

#define MICROPY_PORT_A        (PORT_PA00 | PORT_PA01)
#define MICROPY_PORT_B        (0)
#define MICROPY_PORT_C        (0)

#define IGNORE_PIN_PA12     1
#define IGNORE_PIN_PA13     1
#define IGNORE_PIN_PA17     1
#define IGNORE_PIN_PA18     1
#define IGNORE_PIN_PA19     1
#define IGNORE_PIN_PA20     1
#define IGNORE_PIN_PA21     1
#define IGNORE_PIN_PA22     1
#define IGNORE_PIN_PA23     1
// USB is always used internally so skip the pin objects for it.
#define IGNORE_PIN_PA24     1
#define IGNORE_PIN_PA25     1
#define IGNORE_PIN_PA28     1
#define IGNORE_PIN_PA30     1
#define IGNORE_PIN_PA31     1
#define IGNORE_PIN_PB01     1
#define IGNORE_PIN_PB02     1
#define IGNORE_PIN_PB03     1
#define IGNORE_PIN_PB04     1
#define IGNORE_PIN_PB05     1
#define IGNORE_PIN_PB06     1
#define IGNORE_PIN_PB07     1
#define IGNORE_PIN_PB08     1
#define IGNORE_PIN_PB09     1
#define IGNORE_PIN_PB10     1
#define IGNORE_PIN_PB11     1
#define IGNORE_PIN_PB12     1
#define IGNORE_PIN_PB13     1
#define IGNORE_PIN_PB14     1
#define IGNORE_PIN_PB15     1
#define IGNORE_PIN_PB16     1
#define IGNORE_PIN_PB17     1
#define IGNORE_PIN_PB22     1
#define IGNORE_PIN_PB23     1
#define IGNORE_PIN_PB30     1
#define IGNORE_PIN_PB31     1
#define IGNORE_PIN_PB00     1

#define DEFAULT_I2C_BUS_SCL (&pin_PA09)
#define DEFAULT_I2C_BUS_SDA (&pin_PA08)

#define DEFAULT_SPI_BUS_SCK (&pin_PA07)
#define DEFAULT_SPI_BUS_MOSI (&pin_PA06)
#define DEFAULT_SPI_BUS_MISO (&pin_PA09)

#define DEFAULT_UART_BUS_RX (&pin_PA07)
#define DEFAULT_UART_BUS_TX (&pin_PA06)

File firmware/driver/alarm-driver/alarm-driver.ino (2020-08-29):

/*
Copyright (c) 2020, Riley Rainey

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
THE SOFTWARE IS PROVIDED "AS IS", WITHOUT WARRANTY OF ANY KIND, EXPRESS OR
IMPLIED, INCLUDING BUT NOT LIMITED TO THE WARRANTIES OF MERCHANTABILITY,
FITNESS FOR A PARTICULAR PURPOSE AND NONINFRINGEMENT. IN NO EVENT SHALL THE
AUTHORS OR COPYRIGHT HOLDERS BE LIABLE FOR ANY CLAIM, DAMAGES OR OTHER
LIABILITY, WHETHER IN AN ACTION OF CONTRACT, TORT OR OTHERWISE, ARISING FROM,
OUT OF OR IN CONNECTION WITH THE SOFTWARE OR THE USE OR OTHER DEALINGS IN THE
SOFTWARE.
*/
#include <Arduino.h>
#include <Wire.h>

#define DRIVER_VERSION 1
#define I2C_ADDRESS    0x38

#define PIN_RED_LED  13

// consult variant.cpp for the dskymatic_m0 board definition
// to see how digital pins were added

#define PA_PIN(x) (23+(x))

#define LMAP_IGNORE 255
#define LMAP_SIZE 14

/*
 * Output definitions valid for V3 and later board
 */
const uint8_t l_map[LMAP_SIZE] = {
  PA_PIN(2),
  PA_PIN(3),
  PA_PIN(4),
  PA_PIN(5),
  PA_PIN(19),
  PA_PIN(22), // lamp not populated on board
  PA_PIN(23), // lamp not populated on board
  PA_PIN(27),
  PA_PIN(11),
  PA_PIN(14),
  PA_PIN(15),
  PA_PIN(16),
  PA_PIN(17),
  PA_PIN(18)
};

uint16_t last_command = 0;

void updateLamps(uint16_t command) {
  
  uint16_t check_bit = 0x8000;
  
  for (int i=0; i<LMAP_SIZE; ++i) {

    uint16_t changed = last_command ^ command;
    
    if (l_map[i] != LMAP_IGNORE) {
      if ((changed & check_bit) != 0) {
        digitalWrite(l_map[i], (command & check_bit) ? HIGH : LOW );
      }
    }
    check_bit >>= 1;
  }

  last_command = command;
}

void receiveEvent(int count)
{
  uint16_t command = 0;
  int i = 0;
  while(Wire.available())
  {
    if (i++ < 2) {
      command = (command << 8) | Wire.read();
    }
  }
  if (i == 2) {
    updateLamps(command);
  }
}

void setup() 
{
  pinMode(PIN_RED_LED, OUTPUT);
  digitalWrite(PIN_RED_LED, HIGH);

  /*
   * Turn off all lamps
   */
  for(int i=0; i<LMAP_SIZE; ++i) {
    if (l_map[i] != LMAP_IGNORE) {
      pinMode( l_map[i], OUTPUT );
      digitalWrite( l_map[i], LOW );
    }
  }

  last_command = 0;

  /* 
   *  Connect to I2C Bus
   */
  Wire.begin( I2C_ADDRESS );
  Wire.onReceive( receiveEvent );
}

void loop() {
  delay(50);
}

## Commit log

2020-02-25 Fleshed-out project tree
    [DSKY_alarm.kicad_pcb, DSKY_alarm.sch, Frame.step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]
2020-04-05 Version 4 of the board
    [DSKY_alarm-B_Mask.gbr, DSKY_alarm-B_Paste.gbr, DSKY_alarm-B_SilkS.gbr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]
2020-04-05 add starter firmware and circuitpython board definition
2020-06-29 Add initial glass-to-PCB epoxy mask
2020-07-09 Updated V4 board to a two layer design
    [DSKY_alarm.kicad_pcb, DSKY_alarm.sch]
2020-07-09 Update version info and schematic PDF
    [DSKY_alarm.sch]
2020-07-09 Cleanup of schematic files
    [DSKY_alarm.sch]
2020-08-23 add initial test driver
2020-08-29 functional driver

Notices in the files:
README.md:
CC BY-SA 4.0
